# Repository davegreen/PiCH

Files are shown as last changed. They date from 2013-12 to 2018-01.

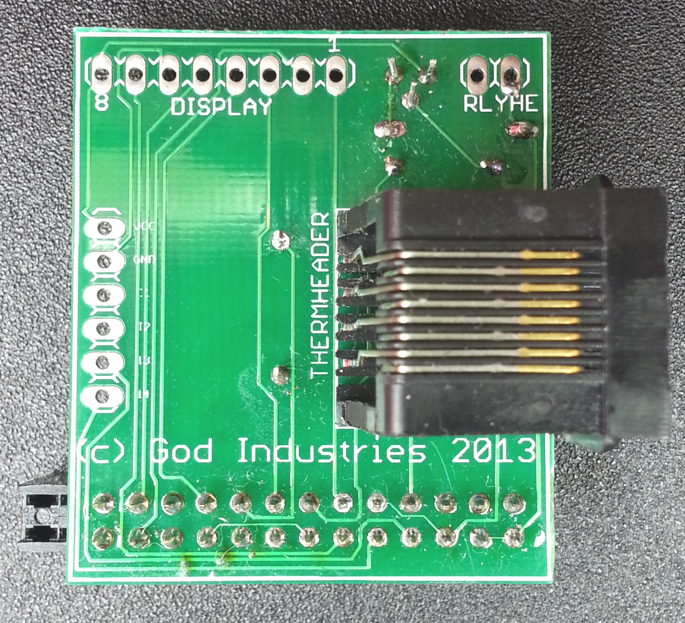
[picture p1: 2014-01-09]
board/images/populated breakout board top.jpg

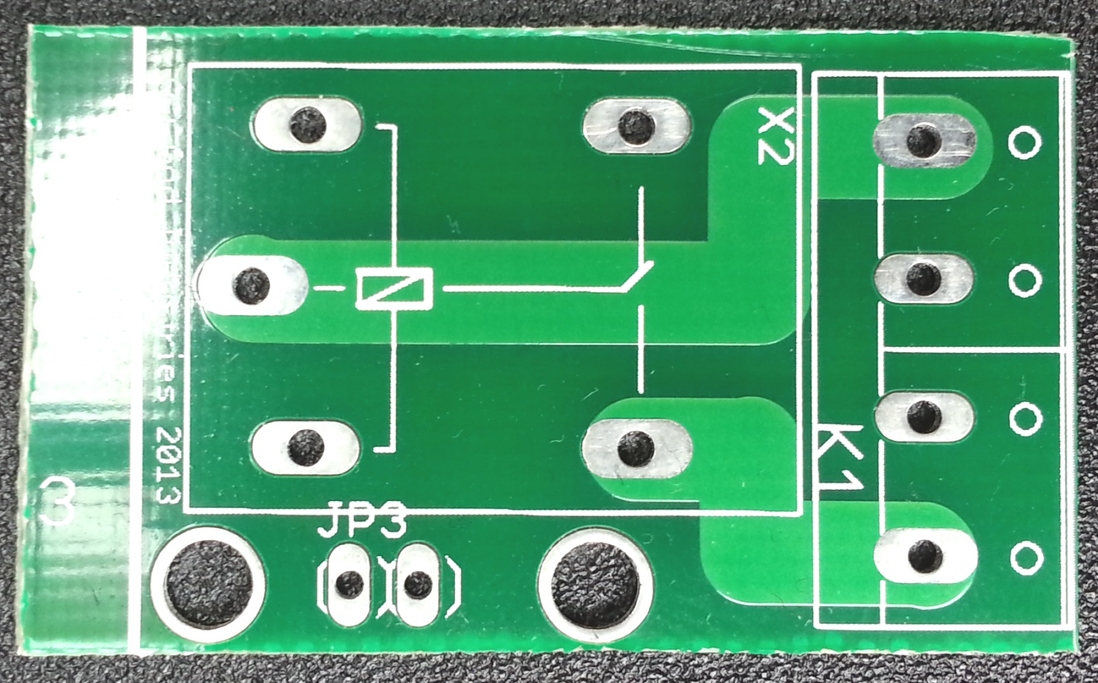
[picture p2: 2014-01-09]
board/images/unpopulated relay board.jpg

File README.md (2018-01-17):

PiCH
====================
PiCentralHeating - A combo hardware/software project for a low cost central 
heating system controller, designed to run on the Raspberry Pi.

Objectives
---------------------
Our key objectives of the PiCH project are:

- Control your heating from anywhere
- Define which area you want to be heat at a given time.

Obviously there are other products that enable you to do this, side objectives include:

- Low setup cost
- Small form factor
- Easily customisable
- Simple enough to use without a PC
- Scalable to lots of sensors
- Weather compensation
- Temperature history graphing and schedule histories.

Description
---------------------
This software is written in a couple of different pieces. The first piece is written in Python and deals with core 
functionality, like reading and logging temperature. The second part is a web interface written in PHP and deals 
primarily with the user interface and management of the system.

If you have any improvements at all please go ahead and make them, then submit a pull request!
If you can't do that, at least let us know what you would like to see.

### Core functionality (Python)

- Reads data from the temperature sensors.
- Writes information about the sensors and temperature to a MySQL database.
- Manages the heating system, turning the boiler on and off to keep to the target temperature.
- Displays the temp (in degrees centigrade) to one decimal place on 3 7-segment LED displays (e.g. 19.8)

### Web interface

- Display current and historical temperature data in the web interface.
- Allow management and naming of the temperature sensors plugged in.
- Scheduling and rule creation for heating system control.
- Easy management of other system settings and features.

PiCH temperature logging page

### Hardware

PiCH temperature board
PiCH temperature and breakout board

TODO
---------------------
See the wiki page: https://github.com/davegreen/PiCH/wiki/TODO

Setting Up
---------------------

There's a few things that need to be done for a successful setup, some of which is currently covered in the [setup script](https://github.com/davegreen/PiCH/blob/master/setup/setup.sh).

At the moment, the web interface and the database both require manual setup. This needs a little linux knowledge to do, but isn't too difficult and will be done during the setup process at some point.

The www files need setting up on a web server locally on the Pi, with PHP5.
The database schema is included in the setup folder (pich-structure.sql). This needs to be MySQL (or compatible) and is connected to by both PHP (db.php) and Python (settings.py).

Running
---------------------

Once things are set up, you can run bootscrip.sh to sort things out ready for everything to go, then run watchdog.py to start monitoring. At some point, this will be put into init, so that it starts with the RPi if you want.

thermostat.sh will get run by cron at schedule start (once a schedule has been created in the web interface) and keep running till the schedule is finished. There's currently no way (short of running killtherm.sh) to stop a running schedule (yes, this is another TODO).

Thanks
---------------------
- [RaspberryPi](http://www.raspberrypi.org) - For making it possible.
- [Bootstrap](https://github.com/twbs/bootstrap) - For making things look good.
- [WiringPi](https://github.com/WiringPi) - For making it easy to use the GPIO pins.

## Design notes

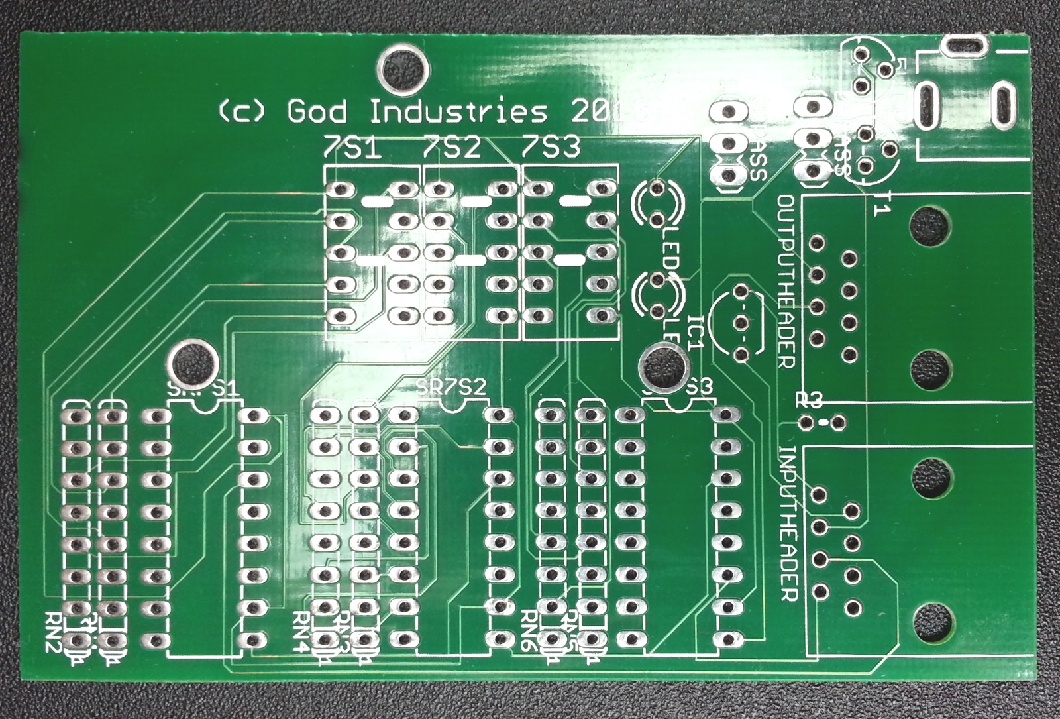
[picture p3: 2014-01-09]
board/images/unpopulated temperature board.jpg

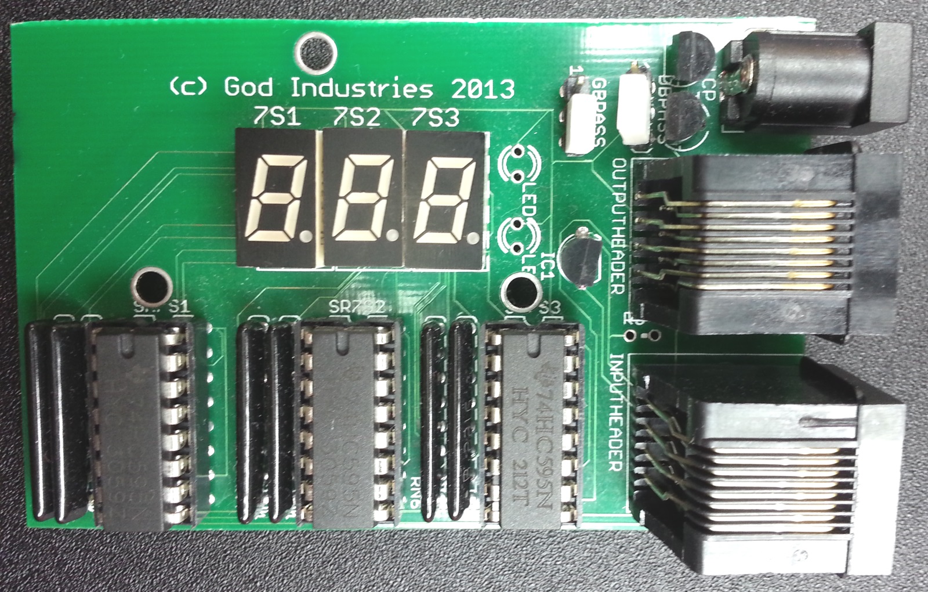
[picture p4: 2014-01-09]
board/images/populated temperature board.jpg

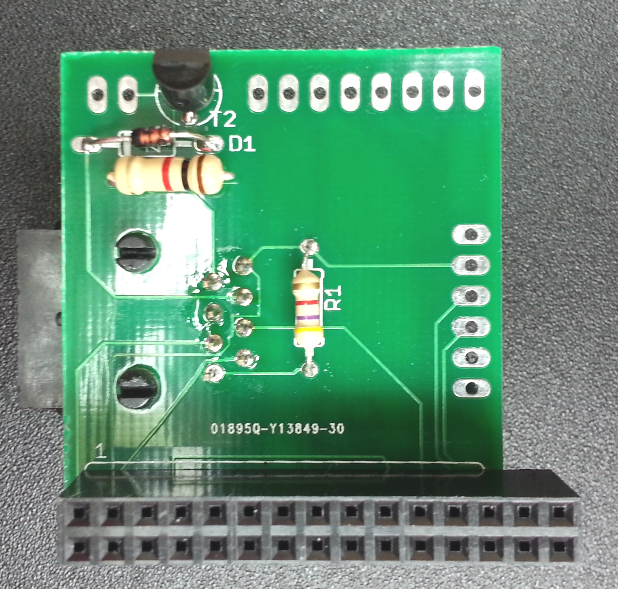
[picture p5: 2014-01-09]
board/images/populated breakout board bottom.jpg

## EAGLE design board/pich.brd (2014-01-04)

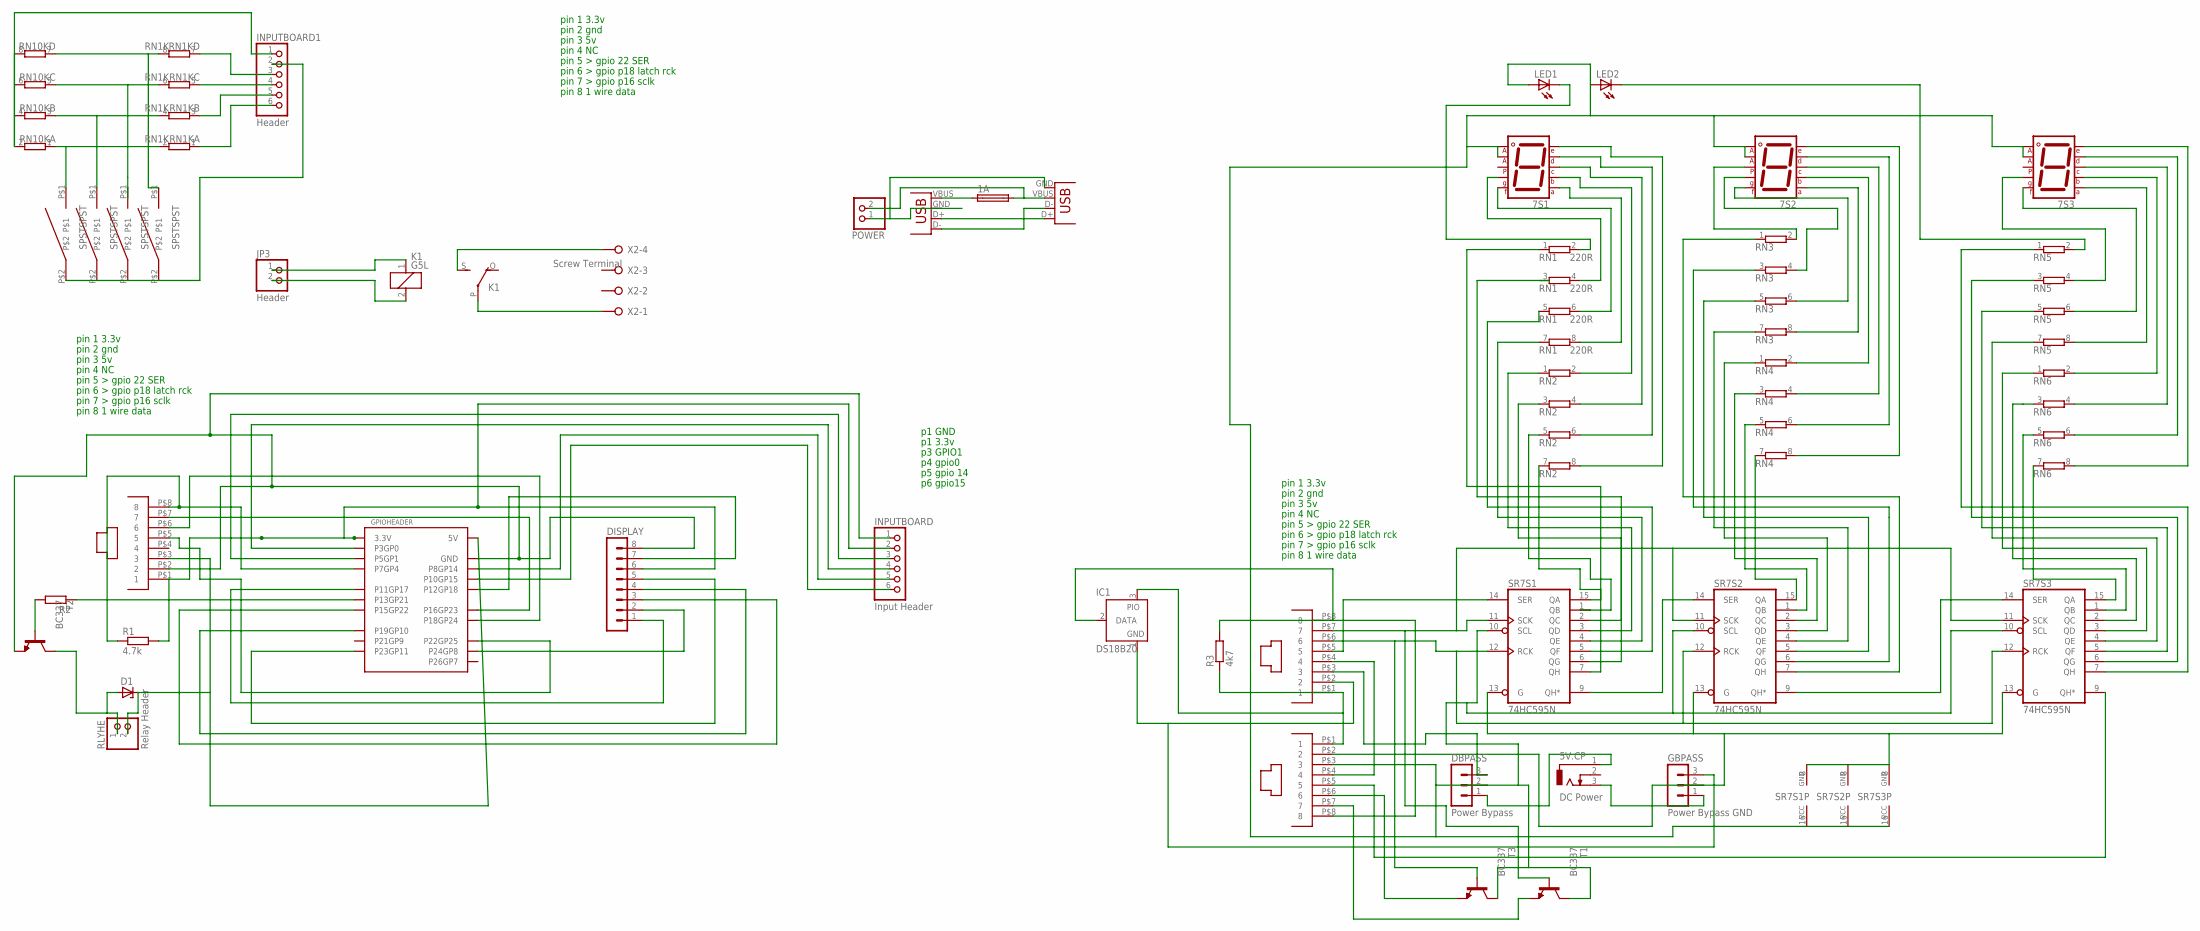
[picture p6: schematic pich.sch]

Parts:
1A: QPL
5V.CP: DC Power; DCJ0303
7S1, 7S2, 7S3: 7SEG-MCA; 7SEG-7
.: USB-A-H
D1: 1N821; DO35Z10
DBPASS: Power Bypass; MA03-1
DISPLAY: MA08-1
GBPASS: Power Bypass GND; MA03-1
GPIOHEADER: GPIOGPIOHEADER; FE13-2
IC1: DS18B20; TO92-
INPUTBOARD: Input Header; 1X06
INPUTBOARD1: Header; 1X06
INPUTHEADER: ETHERNETTRUCONNECTRAPID; ETHERNET
JP3: Header; 1X02
K1: G5L; G5LE
LED1, LED2: LED3MM
OUTPUTHEADER: ETHERNETTRUCONNECTRAPID; ETHERNET
POWER: PINHD-1X2; 1X02
R1: 4.7k; 0207/10
R2: R-EU_0204/7; 0204/7
R3: 4k7; 0204V
RLYHE: Relay Header; 1X02
RN1: 220R; SIL8
RN1K: RN1K; SIL8
RN2, RN3, RN4, RN5, RN6: E4RP; SIL8
RN10K: E4R; SIL8
SR7S1, SR7S2, SR7S3: 74HC595N; DIL16
T1, T2, T3: BC337; TO92
THERMHEADER: ETHERNETTRUCONNECTRAPID; ETHERNET
U$2, U$3, U$4, U$5: SPSTSPST; MAPLINSWITCH
X1: USB-A-HU
X2: Screw Terminal; W237-4P

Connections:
GND: DISPLAY.8, GPIOHEADER.6 (GND), GPIOHEADER.9 (GND), GPIOHEADER.14 (GND), GPIOHEADER.20 (GND), GPIOHEADER.25 (GND), INPUTBOARD.1, T2.1 (E), THERMHEADER.P$2 (2)
GND1: ..GND (VBUS), POWER.1, X1.GND
GPIO4W1DATA: GPIOHEADER.7 (P7GP4), R1.1, THERMHEADER.P$8 (8)
unnamed: 1A.2, POWER.2, X1.VBUS
unnamed: D1.C, GPIOHEADER.2 (5V), GPIOHEADER.4 (5V), RLYHE.2, THERMHEADER.P$3 (3)
unnamed: DISPLAY.7, GPIOHEADER.12 (P12GP18)
unnamed: DISPLAY.1, GPIOHEADER.11 (P11GP17)
unnamed: DISPLAY.5, GPIOHEADER.23 (P23GP11)
unnamed: DISPLAY.4, GPIOHEADER.19 (P19GP10)
unnamed: DISPLAY.3, GPIOHEADER.15 (P15GP22)
unnamed: DISPLAY.2, GPIOHEADER.24 (P24GP8)
unnamed: GPIOHEADER.16 (P16GP23), THERMHEADER.P$7 (7)
unnamed: GPIOHEADER.18 (P18GP24), THERMHEADER.P$6 (6)
unnamed: GPIOHEADER.22 (P22GP25), THERMHEADER.P$5 (5)
unnamed: D1.A, RLYHE.1, T2.3 (C)
unnamed: GPIOHEADER.13 (P13GP21), R2.1
unnamed: R2.2, T2.2 (B)
unnamed: JP3.1, K1.1
unnamed: JP3.2, K1.2
unnamed: GPIOHEADER.3 (P3GP0), INPUTBOARD.4
unnamed: GPIOHEADER.8 (P8GP14), INPUTBOARD.5
unnamed: GPIOHEADER.5 (P5GP1), INPUTBOARD.3
unnamed: GPIOHEADER.10 (P10GP15), INPUTBOARD.6
unnamed: K1.P, X2.1
unnamed: K1.S, X2.4
unnamed: SR7S1.9 (QH*), SR7S2.14 (SER)
unnamed: IC1.3 (PIO), INPUTHEADER.P$1 (1), OUTPUTHEADER.P$1 (1), R3.1
unnamed: GBPASS.2, OUTPUTHEADER.P$2 (2), SR7S1.8 (GND), SR7S1.13 (G), SR7S2.8 (GND), SR7S2.13 (G), SR7S3.8 (GND), SR7S3.13 (G)
unnamed: INPUTHEADER.P$4 (4), OUTPUTHEADER.P$4 (4)
unnamed: INPUTHEADER.P$5 (5), SR7S1.14 (SER)
unnamed: INPUTHEADER.P$6 (6), SR7S1.12 (RCK), SR7S2.12 (RCK), SR7S3.12 (RCK), T3.2 (B)
unnamed: IC1.2 (DATA), INPUTHEADER.P$8 (8), OUTPUTHEADER.P$8 (8), R3.2
unnamed: SR7S2.9 (QH*), SR7S3.14 (SER)
unnamed: LED1.K (C), RN1.2
unnamed: 7S1.3 (G), RN1.4 (2)
unnamed: 7S1.2 (F), RN1.6 (2)
unnamed: 7S1.10 (A), RN1.8 (2)
unnamed: 7S1.9 (B), RN2.2
unnamed: 7S1.8 (C), RN2.4 (2)
unnamed: 7S1.5 (D), RN2.6 (2)
unnamed: 7S1.4 (E), RN2.8 (2)
unnamed: RN2.7 (1), SR7S1.15 (QA)
unnamed: RN2.5 (1), SR7S1.1 (QB)
unnamed: RN2.3 (1), SR7S1.2 (QC)
unnamed: RN2.1, SR7S1.3 (QD)
unnamed: RN1.7 (1), SR7S1.4 (QE)
unnamed: RN1.5 (1), SR7S1.5 (QF)
unnamed: RN1.3 (1), SR7S1.6 (QG)
unnamed: RN1.1, SR7S1.7 (QH)
unnamed: GBPASS.3, IC1.1 (GND), INPUTHEADER.P$2 (2)
unnamed: 7S2.7 (DP), RN3.2
unnamed: 7S2.3 (G), RN3.4 (2)
unnamed: 7S2.2 (F), RN3.6 (2)
unnamed: 7S2.10 (A), RN3.8 (2)
unnamed: 7S2.9 (B), RN4.2
unnamed: 7S2.8 (C), RN4.4 (2)
unnamed: 7S2.5 (D), RN4.6 (2)
unnamed: 7S2.4 (E), RN4.8 (2)
unnamed: RN4.7 (1), SR7S2.15 (QA)
unnamed: RN4.5 (1), SR7S2.1 (QB)
unnamed: RN4.1, SR7S2.3 (QD)
unnamed: RN3.7 (1), SR7S2.4 (QE)
unnamed: RN3.3 (1), SR7S2.6 (QG)
unnamed: RN3.1, SR7S2.7 (QH)
unnamed: LED2.K (C), RN5.2
unnamed: 7S3.3 (G), RN5.4 (2)
unnamed: 7S3.2 (F), RN5.6 (2)
unnamed: 7S3.10 (A), RN5.8 (2)
unnamed: 7S3.9 (B), RN6.2
unnamed: 7S3.8 (C), RN6.4 (2)
unnamed: 7S3.5 (D), RN6.6 (2)
unnamed: 7S3.4 (E), RN6.8 (2)
unnamed: RN6.7 (1), SR7S3.15 (QA)
unnamed: RN6.5 (1), SR7S3.1 (QB)
unnamed: RN6.3 (1), SR7S3.2 (QC)
unnamed: RN6.1, SR7S3.3 (QD)
unnamed: RN5.7 (1), SR7S3.4 (QE)
unnamed: RN5.5 (1), SR7S3.5 (QF)
unnamed: RN5.3 (1), SR7S3.6 (QG)
unnamed: RN5.1, SR7S3.7 (QH)
unnamed: DBPASS.3, INPUTHEADER.P$3 (3)
unnamed: RN4.3 (1), SR7S2.2 (QC)
unnamed: RN3.5 (1), SR7S2.5 (QF)
unnamed: 5V.CP.1, DBPASS.1
unnamed: 5V.CP.3, GBPASS.1
unnamed: 7S1.1 (CA1), 7S1.6 (CA2), 7S2.1 (CA1), 7S2.6 (CA2), 7S3.1 (CA1), 7S3.6 (CA2), DBPASS.2, LED1.A, LED2.A, OUTPUTHEADER.P$3 (3), SR7S1.10 (SCL), SR7S1.16 (VCC), SR7S2.10 (SCL), SR7S2.16 (VCC), SR7S3.10 (SCL), SR7S3.16 (VCC), T1.3 (C), T3.3 (C)
unnamed: OUTPUTHEADER.P$5 (5), SR7S3.9 (QH*)
unnamed: 1A.1, ..VBUS (GND)
unnamed: ..D- (D+), X1.D-
unnamed: ..D+ (D-), X1.D+
unnamed: OUTPUTHEADER.P$7 (7), T1.1 (E)
unnamed: RN1K.8 (2), RN10K.7 (1), U$5.P$1
unnamed: INPUTBOARD1.1, RN10K.2, RN10K.4 (2), RN10K.6 (2), RN10K.8 (2)
unnamed: INPUTBOARD1.3, RN1K.7 (1)
unnamed: INPUTBOARD1.4, RN1K.5 (1)
unnamed: INPUTBOARD1.5, RN1K.3 (1)
unnamed: INPUTBOARD1.6, RN1K.1
unnamed: INPUTBOARD1.2, U$2.P$2, U$3.P$2, U$4.P$2, U$5.P$2
unnamed: RN1K.6 (2), RN10K.5 (1), U$4.P$1
unnamed: RN1K.4 (2), RN10K.3 (1), U$3.P$1
unnamed: RN1K.2, RN10K.1, U$2.P$1
unnamed: INPUTHEADER.P$7 (7), SR7S1.11 (SCK), SR7S2.11 (SCK), SR7S3.11 (SCK), T1.2 (B)
unnamed: OUTPUTHEADER.P$6 (6), T3.1 (E)
VCC: DISPLAY.6, GPIOHEADER.1 (3.3V), GPIOHEADER.17 (3.3V), INPUTBOARD.2, R1.2, THERMHEADER.P$1 (1)

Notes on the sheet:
pin 1 3.3v
pin 2 gnd
pin 3 5v
pin 4 NC
pin 5 > gpio 22 SER
pin 6 > gpio p18 latch rck
pin 7 > gpio p16 sclk
pin 8 1 wire data
p1 GND
p1 3.3v
p3 GPIO1
p4 gpio0
p5 gpio 14
p6 gpio15

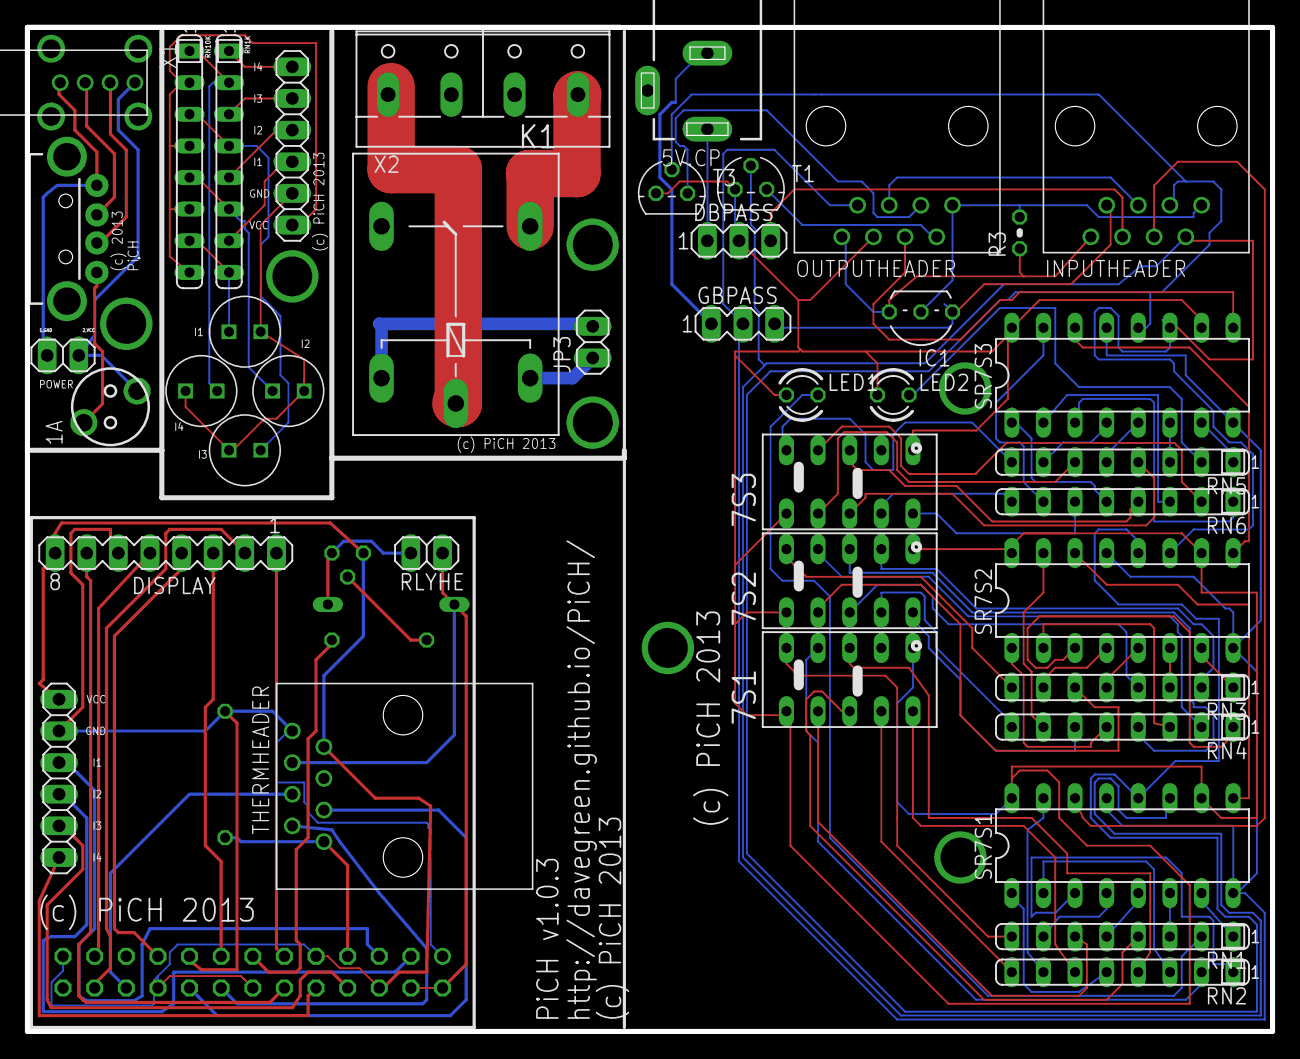
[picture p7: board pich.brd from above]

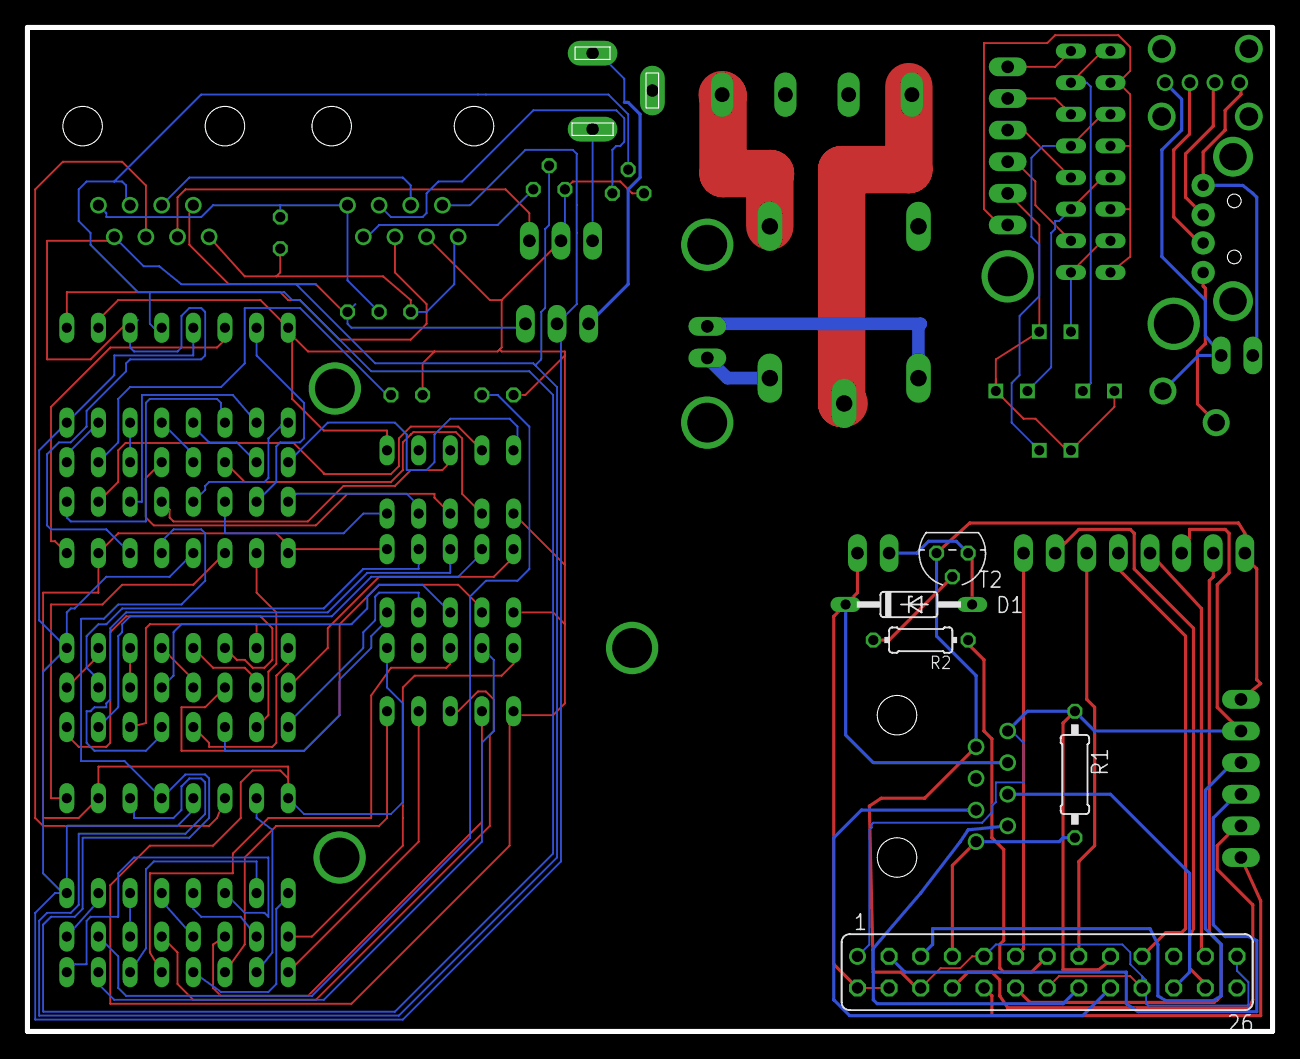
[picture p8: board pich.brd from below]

Board: 4 copper layers, 100.0 x 80.6 mm, 46 parts (5 on the bottom side), 104 nets.

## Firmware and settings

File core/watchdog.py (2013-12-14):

#!/usr/bin/python

import settings
import glob
import time
import MySQLdb 
import wiringpi
import settings
from time import sleep

_time = float(0)
_buffer = "" #buffer for the shift outputs

#this is the setup for the tempaurature array. it is currently called something stupid
#and it could probably do with being in a differnt file. not sure if that can be done though
_temp = []
_temp.append("1000000")#zero
_temp.append("1110011")#one
_temp.append("0100100")#2
_temp.append("0100001")#3
_temp.append("0010011")#4
_temp.append("0001001")#5
_temp.append("0001000")#6
_temp.append("1100011")#7
_temp.append("0000000")#8
_temp.append("0000001")#9
_DPTRUE = "0"
_DPFALSE = "1"

#set the pins to output, then set them all to high, so that we should have blank 7 segments
io = wiringpi.GPIO(wiringpi.GPIO.WPI_MODE_SYS)
io.pinMode(settings._DATA,io.OUTPUT)
io.pinMode(settings._DATACLK,io.OUTPUT)
io.pinMode(settings._LATCH,io.OUTPUT)
io.digitalWrite(settings._DATA,1)
io.digitalWrite(settings._DATACLK,1)
io.digitalWrite(settings._LATCH,1)

def shiftout(outputstring):
	#this is the function that actually shifts its out, latch low, then clk line oscillates, low high per bit to the data line
	i = 0
	io.digitalWrite(settings._LATCH, io.LOW)
		
	while i < len(outputstring):
		io.digitalWrite(settings._DATACLK,io.LOW)
		sleep(settings._DELAY)
		io.digitalWrite(settings._DATA,int(outputstring[i]))
		io.digitalWrite(settings._DATACLK,io.HIGH)
		sleep(settings._DELAY)
		i = i + 1
			
	io.digitalWrite(settings._LATCH, io.HIGH)
	io.digitalWrite(settings._DATA,io.HIGH)
	#print outputstring
	#latch needs to go high at the end, or the registers ignore the data
	
def outputshiftstring():
	global _buffer
	#output the string then clear the buffer
	#print "outputting now " + _buffer
	shiftout(_buffer)
	_buffer = ""

def appendstring(inputnumber, decimalpoint):
	global _buffer
	#appends the information to the main output buffer. need to be careful as im not sure which way these will work when another set of SR are in circuit
	_buffer = _buffer + str(decimalpoint) + str(_temp[inputnumber])

def preptemp(inputtemp):
	
	if len(inputtemp) > 3:
		#take the temperature and split it out to the append string function
		appendstring(int(inputtemp[3]),_DPFALSE)
		appendstring(int(inputtemp[1]),_DPTRUE)
		appendstring(int(inputtemp[0]),_DPFALSE)

def read_temp_raw(devid):
	#try to read the temperature sensor, based on devid, if it fails, mark it as dead, else return the data.
	
	try:
	    f = open(settings.base_dir + devid + settings.device_file, 'r')
	    lines = f.readlines()
	    f.close()
	    return lines
	
	except:
		#not sure why this is commented out atm
		#SQL_MarkDeadSensor(devid)
		return "fail"

def RetrieveSQLOffset(devid):
	db = MySQLdb.connect(host=settings.SQLSERVER,user=settings.SQLUSER,passwd=settings.SQLPASS,db=settings.SQLDB,port=settings.SQLPORT)
	cursor = db.cursor()
	sql = "SELECT `offset` FROM `sensors` WHERE `uid` = '" + devid + "' LIMIT 1"
	cursor.execute(sql)
	result = cursor.fetchall()
	db.close
	return result[0]

def read_temp(uid, devid):
	global _time
	#get data from the raw function
	lines = read_temp_raw(devid)
	
	if lines == "fail" :
		return 0
	
	else :
		i = 0
		#this is a CRC check, if it fails, it will try 5 times, then give up thinking it has a dead sensor
		
		while lines[0].strip()[-3:] != 'YES':
			time.sleep(0.2)
			lines = read_temp_raw(devid)
			
			if i > 5 :
				return 0
			
			else :
				i = i + 1
				
		#print lines	
		equals_pos = lines[1].find('t=')
		#check the tempurature for some weird shit, then log it out to SQL, and also prepare for the round of shifting out.
		#need to add in a little check, as not all sensors will shift out....
		result = SQL_Read_EnabledSensors(devid)
		
		if equals_pos != -1:
			temp_string = lines[1][equals_pos+2:]
			temp_c = float(temp_string) / 1000.0
			offset = RetrieveSQLOffset(devid)
			temp_c = temp_c + float(offset[0])
			
			if result > 0:
				preptemp(str(temp_c))
			
			if time.time() > _time + float(60):
				SQL_LogTemp(devid,uid,temp_c)
				_time = time.time()
		return 1

def read_device_list():
	#reads out the devices from the bus master files, writes them out to the sql DB
	f = open ("/sys/bus/w1/devices/w1_bus_master1/w1_master_slaves", "r" )
	lines = f.readlines()
	i = 0
	
	for each in lines :
		SQL_Write_DevID(lines[i][:15])
		i = i + 1
		
	return 0

def SQL_Write_DevID(devid):
	db = MySQLdb.connect(host=settings.SQLSERVER,user=settings.SQLUSER,passwd=settings.SQLPASS,db=settings.SQLDB,port=settings.SQLPORT )
	cursor = db.cursor()
	#writing out the devid of the sensors, trys to update first, in the case of a dead sensor coming back online.
	
	try:
		sql = "INSERT INTO `sensors` (`uid`, `enabled`) VALUES ('" + devid + "', '1');"
		cursor.execute(sql)
		db.commit()
		
	except:
		try:
			sql = "UPDATE `sensors` SET `enabled` =  '1' WHERE `uid` = '" + str(devid) + "'"
			cursor.execute(sql)
			db.commit()
			
		except:
			db.rollback
	
	db.close
	
def SQL_Read_EnabledSensors(devid):
	#this function uses SQL to get the DevIDs, and then read each tempurature sensor in turn.
	db = MySQLdb.connect(host=settings.SQLSERVER,user=settings.SQLUSER,passwd=settings.SQLPASS,db=settings.SQLDB,port=settings.SQLPORT)
	cursor = db.cursor()
	sql = "SELECT `uid` FROM `sensors` WHERE `uid` = '" + devid + "' AND `enabled` = 1 AND `output` = 1 LIMIT 1"
	cursor.execute(sql)
	result = cursor.rowcount
	db.close
	return result

def SQL_Read_DevID():
	#this function uses SQL to get the DevIDs, and then read each tempurature sensor in turn.
	db = MySQLdb.connect(host=settings.SQLSERVER,user=settings.SQLUSER,passwd=settings.SQLPASS,db=settings.SQLDB,port=settings.SQLPORT)
	cursor = db.cursor()
	sql = "SELECT `uid` , `device` FROM `sensors` WHERE `enabled` = 1 ORDER BY `sequence` ASC"
	cursor.execute(sql)
	results = cursor.fetchall()
	
	for row in results:
		uid = row[0]
		devid = row[1]
		# Now print fetched result
			
		if read_temp (str(devid),str(uid)) == 0 :
			SQL_MarkDeadSensor(devid)
			
	db.close
	outputshiftstring()
				
def SQL_LogTemp(devid, uid, temp):
	#as it says on the tin, connects to the SQL server, and puts in the data its passed
	db = MySQLdb.connect(host=settings.SQLSERVER,user=settings.SQLUSER,passwd=settings.SQLPASS,db=settings.SQLDB,port=settings.SQLPORT)
	cursor = db.cursor()	
	sql = "INSERT INTO `temperature` (`sensor` ,`temperature` ,`timestamp`) VALUES ('" + devid + "','" + str(temp) + "',CURRENT_TIMESTAMP);"
	cursor.execute(sql)
	db.commit()
	data = cursor.fetchall()
	db.close
	return

def SQL_MarkDeadSensor(sensorID):
	#in the event that watchdog cant get the data out of a sensor(unplugged, or 5 CRC errors, or faulty) it calls this function
	#just connects to the SQL, and marks the sensor as disabled
	db = MySQLdb.connect(host=settings.SQLSERVER,user=settings.SQLUSER,passwd=settings.SQLPASS,db=settings.SQLDB,port=settings.SQLPORT)
	cursor = db.cursor()
	sql = "UPDATE `sensors` SET `enabled` =  '0' WHERE `sensors`.`device` =" + str(sensorID) + " LIMIT 1"
	cursor.execute(sql)
	db.commit()
	data = cursor.fetchall()
	db.close
	return

while True:
	#this reads in the devices, and updates the SQL table, it does this every 5 times through the sensors, to automatically pick up new sensors	
	read_device_list()
	i = 0
	
	while i < 5:
		#read the sensors in from the sqlDB, write out the data back to SQL & shift registers, sit happily in the background, never crash, happy days
		SQL_Read_DevID()
		time.sleep(1)
		i = i + 1

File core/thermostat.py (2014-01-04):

#!/usr/bin/python

from datetime import datetime, time
import wiringpi
import sys
from time import sleep
import MySQLdb
import settings

FINISHTIME = time(0,0,0)
DEVID = ''
TARGETTEMP = ''

if len(sys.argv) != 2:
	print "Usage: ./thermostat.py <scheduleid>"
	sys.exit()

SCHEDULEID = sys.argv[1]
io = wiringpi.GPIO(wiringpi.GPIO.WPI_MODE_SYS)
io.pinMode(settings.ThermPin,io.OUTPUT)


def UpdateHeatingStatus(status):
	db = MySQLdb.connect(host=settings.SQLSERVER,user=settings.SQLUSER,passwd=settings.SQLPASS,db=settings.SQLDB,port=settings.SQLPORT )
	cursor = db.cursor()
	
	try:
		sql = "INSERT INTO `status` (`status`) VALUES ('" + status + "');"
		cursor.execute(sql)
		db.commit()
	
	except:
		db.rollback
		db.close
		
def RetrieveSQLOffset(devid):
	db = MySQLdb.connect(host=settings.SQLSERVER,user=settings.SQLUSER,passwd=settings.SQLPASS,db=settings.SQLDB,port=settings.SQLPORT)
	cursor = db.cursor()
	sql = "SELECT `offset` FROM `sensors` WHERE `uid` = '" + devid + "' LIMIT 1"
	cursor.execute(sql)
	result = cursor.fetchall()
	db.close
	return result[0]

def error_end(reason):
	#in case of an error, handle it by calling this function which kills
	#the sql connection, and sets the pin to low, closing the relay
	io.digitalWrite(settings.ThermPin,io.LOW)
	#db.close
	print reason
	sys.exit()

##############################################################################
#
#  Legacy function for reading direct from the tempurature sensor
#  Removed to read from the SQL DB to allow sensor to be located remotly
#
##############################################################################
#
#def read_temp_raw ():#
#	try:
#		f = open(settings.base_dir + DEVID + settings.device_file, 'r')
#		lines = f.readlines()
#		f.close()
#		return lines
#	
#	except:
#		error_end("sensor dead")
#def read_temp ():
#	lines = read_temp_raw()
#	i = 0
#	
#	while lines[0].strip()[-3:] != 'YES':
#		sleep(0.2)
#		lines = read_temp_raw()
#		
#		if i > 5:
#			error_end("CRC Error")
#		
#		else :
#			i = i + 1
#
#	equals_pos = lines[1].find('t=')
#	
#	if equals_pos != -1:
#		temp_string = lines[1][equals_pos+2:]
#		offset = RetrieveSQLOffset(DEVID)
#		temp_c = float(temp_string) / 1000.0
#		temp_c = temp_c + offset[0]
#		return temp_c


def read_temp():
	global DEVID

	#open database connection
	db = MySQLdb.connect(host=settings.SQLSERVER,user=settings.SQLUSER,passwd=settings.SQLPASS,db=settings.SQLDB,port=settings.SQLPORT )

	# prepare a cursor object using cursor() method
	cursor = db.cursor()	

	SQL = "SELECT `temperature` FROM `temperature` WHERE `sensor` = '" + DEVID + "' ORDER BY `timestamp` DESC LIMIT 1"

	cursor.execute(SQL)
	results = cursor.fetchall()

	cursor.close()
	db.close()

	return results[0][0]


def update_SQL():
	global DEVID
	global TARGETTEMP
	global SCHEDULEID

	try:
		#open database connection
		db = MySQLdb.connect(host=settings.SQLSERVER,user=settings.SQLUSER,passwd=settings.SQLPASS,db=settings.SQLDB,port=settings.SQLPORT )
		
		# prepare a cursor object using cursor() method
		cursor = db.cursor()	
		SQL1 = "SELECT `targettemp`, `sensor` FROM `rules` WHERE `schedule` = " + SCHEDULEID
		SQL2 = "SELECT `timeend` FROM `schedules` WHERE `id` = " + SCHEDULEID	

		cursor.execute(SQL1)
		results = cursor.fetchall()
		DEVID = results[0][1]
		TARGETTEMP = results[0][0]
		cursor.execute(SQL2)
		results = cursor.fetchall()
		split_finish(results[0][0])	
		cursor.close()
		db.close()
	
	except:
		error_end("Schedule Removed????")
	
def split_finish(sqlfinish):
	global FINISHTIME
	t = str(sqlfinish).split(":")
	FINISHHOUR = int(t[0])
	FINISHMIN = int(t[1])
	FINISHSEC = int(t[2])
	FINISHTIME = time(FINISHHOUR,FINISHMIN,FINISHSEC)

update_SQL()
b = True

while b == True:
	update_SQL()	
	UpdateHeatingStatus(1)

	if float(TARGETTEMP) > float(read_temp()):
		io.digitalWrite(settings.ThermPin,io.HIGH)
		
	else:
		io.digitalWrite(settings.ThermPin,io.LOW)
	
	if datetime.time(datetime.now()) > FINISHTIME:
		b = False
#	else:#
	#	b = False
	
	#Sleep is set to not cause the boiler to flick on and off too quickly.
	#Lower values have not been tested.
	sleep(60)
	
print "switching off the heating now"
io.digitalWrite(settings.ThermPin,io.LOW)
UpdateHeatingStatus(0)

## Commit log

2013-12-13 Step to add 1-wire bus modules to /etc/modules so that things work on boot
2013-12-14 Move heating on/off notification to the navbar
2013-12-14 Refactor sensor display/settings page
2013-12-29 First public release of PiCH boards
    [pich.GBL, pich.GBO, pich.GBP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]
2013-12-29 Update folder structure
    [pich.GBL, pich.GBO, pich.GBP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]
2013-12-29 Correct indenting and remove copied comment.
    [thermostat.py]
2014-01-02 Add temperature logging page image
2014-01-04 Move sleep to correct place and change to 60 seconds
    [thermostat.py]
2014-01-04 Now reads current temp from SQL
2014-01-04 Case sensitive web address
    [pich.brd]
2014-01-04 Add running board images
2014-01-09 Added board images

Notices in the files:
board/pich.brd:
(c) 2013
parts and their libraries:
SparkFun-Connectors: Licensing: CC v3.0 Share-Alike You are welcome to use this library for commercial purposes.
